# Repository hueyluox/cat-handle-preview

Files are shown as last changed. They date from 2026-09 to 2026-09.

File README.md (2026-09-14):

# 猫咪桶盖把手 · v3

两款照片参考的卡通猫咪把手，平底约 110 × 44 mm，三色分区。

- `*-A1-AMS.3mf`：拓竹 A1 + AMS lite 工程。
- `*-multicolor.3mf`：通用三色模型。
- `*-single.stl`：单色整体模型。

颜色顺序：1 暖白，2 橘色，3 深棕。使用 A1 工程前请按实际耗材重新切片。
模型尚未实物试打，粘贴前需检查桶盖平面尺寸和把手间隙。

在线预览：https://hueyluox.github.io/cat-handle-preview/

新作：不许上班 · 双猫屏幕摆件
- 页面：https://hueyluox.github.io/cat-handle-preview/monitor-cats/

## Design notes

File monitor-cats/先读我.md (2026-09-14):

# 不许上班 · 双猫屏幕摆件 v1

这是实际模型交付包，不是生成式效果图。猫的外形为照片参考的三色简化雕塑，尚未实物试打。

## 对应你家的两只猫
- 橘白：橘耳、橘色头顶和后背，窄白鼻纹、白胸、白前爪；条纹为浅凹槽。
- 三花：身体与整个后背全部白色，仅头和尾巴有橘/黑花纹，尾巴贴身。
- 全部模型只使用白、橘、黑三色。AMS lite 建议槽位 1 白、2 橘、3 黑。

## 从哪里开始
1. 先打印 `mounts/fit-check-16mm-PRINT.stl`。用户测量屏幕顶部厚度 15 mm，托座槽宽 16 mm。试槽能自然放上才继续，不能用力挤压显示屏；顶部若有弧度或斜面，仍需实物确认。
2. 两只都打印：用 Bambu Studio 打开 `pair/pair-A1-AMS.3mf`，按你实际的 PLA / PETG 等耗材重新选择材料并切片。目前工程按 Generic PLA 配置。
3. 单独打印可打开 `orange-cat/orange-cat-A1-AMS.3mf` 或 `calico-cat/calico-cat-A1-AMS.3mf`。
4. 白色托座用 `mounts/mounts-A1-white.3mf`，其中包括两只托座和一只试槽件。独立 STL 名称里的 PRINT 表示已设置推荐打印方向。
5. 猫和托座分开打印。清理支撑和边缘后，对齐猫底部浅槽与托座定位凸台，用适量胶或薄双面胶固定。浅槽只负责定位，不是卡扣锁紧结构。固化/贴牢后再安装。

## 文件说明
- `模型预览.html`：可离线打开的真实网格查看器，可转到背面核对纯白身体。
- `双猫-实际模型预览.png`：真实交付网格静态预览。
- `*-A1-AMS.3mf`：已有三色映射并经过实际切片的拓竹工程。
- `*-multicolor.3mf`：通用三色实体模型，便于自行重新配置切片。
- `*-single.stl`：单色整体版，STL 本身不保存颜色。
- `mounts/*-assembly.stl`：装配坐标用，请优先打印 PRINT 文件。
- `source/`：参数化生成脚本、网格预览代码与 A1 配置。

## 尺寸与当前切片估算
- 橘白猫体约 47.4 × 52.4 × 67.7 mm；含托座总高约 85.7 mm。
- 三花猫体约 87.7 × 51.2 × 51.7 mm；含托座总高约 69.7 mm。
- 托座：槽宽 16 mm，对应名义机身厚度 15 mm；橘白托座宽 40 mm，三花宽 60 mm。
- 两只同盘：约 21 小时 56 分钟，293.48 g。两只分别打印合计约 27 小时 6 分钟，363.54 g。
- 白色托座和试槽件：另约 1 小时 22 分钟，20.32 g。
- 上述时间/耗材来自 A1、0.4 mm 喷嘴、0.16 mm 层高、猫体 3 壁/15% gyroid、自动支撑、三色冲刷配置；耗材包含支撑、冲刷与擦料塔。
- 同盘可减少重复换色，但仍有较多冲刷；最终以你设备和耗材重新切片结果为准。

## 已完成的验证与实际限制
- 两只整体网格封闭、正体积、各一个连通实体；三色分件均封闭，复原体积相对误差小于 0.001%。
- 三花背部上方区域的有色实体相交体积为 0；已检查实际网格背面预览。
- 托座 16 mm 通槽、底部定位配合通过几何检查。
- 两个单猫工程、两猫同盘工程、白色托座工程均已用 Bambu Studio 2.8.2.61 实际切片，并确认没有超出打印区域。
- 尚未实物打印，托座适配、表面效果、去支撑难度、装配稳定性需通过试打确认。

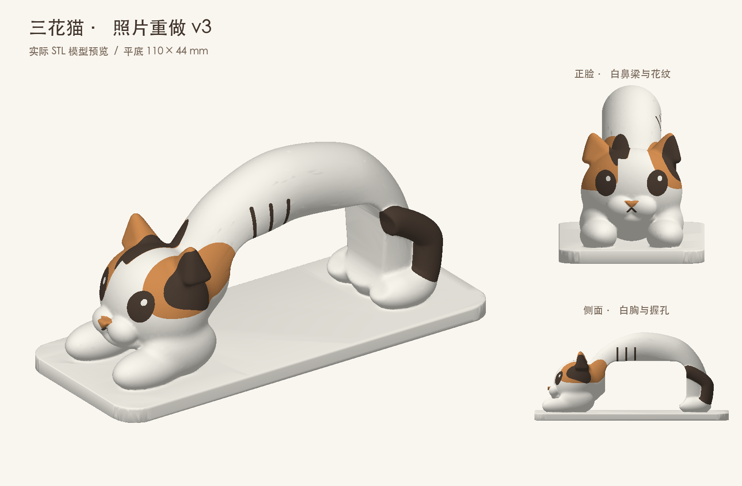
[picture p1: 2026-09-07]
previews/calico-cat.png

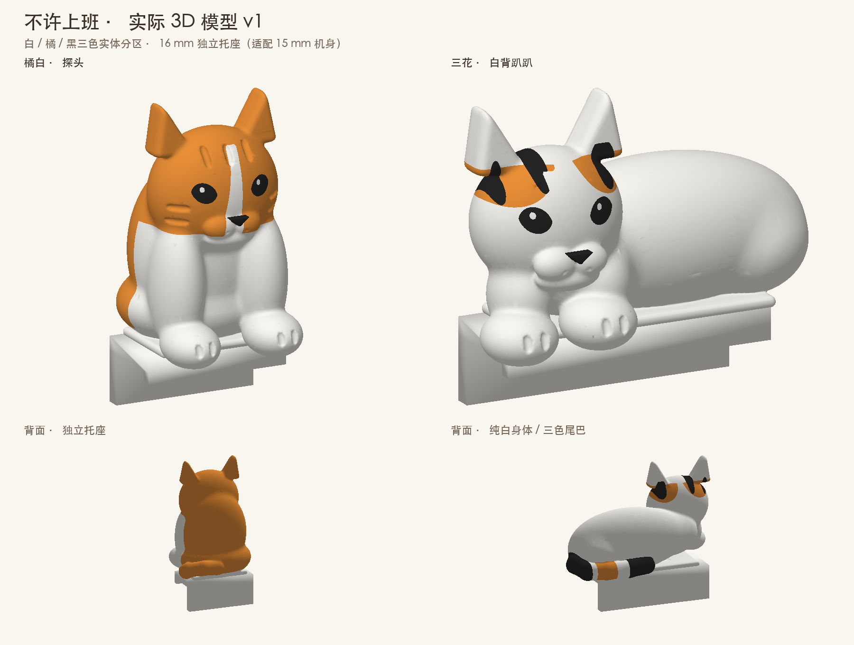
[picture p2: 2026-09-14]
monitor-cats/双猫-实际模型预览.png

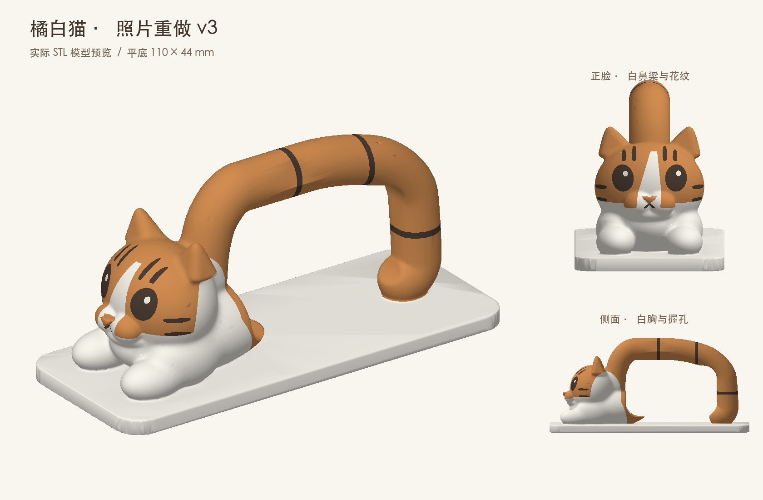
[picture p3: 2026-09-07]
previews/orange-cat.png

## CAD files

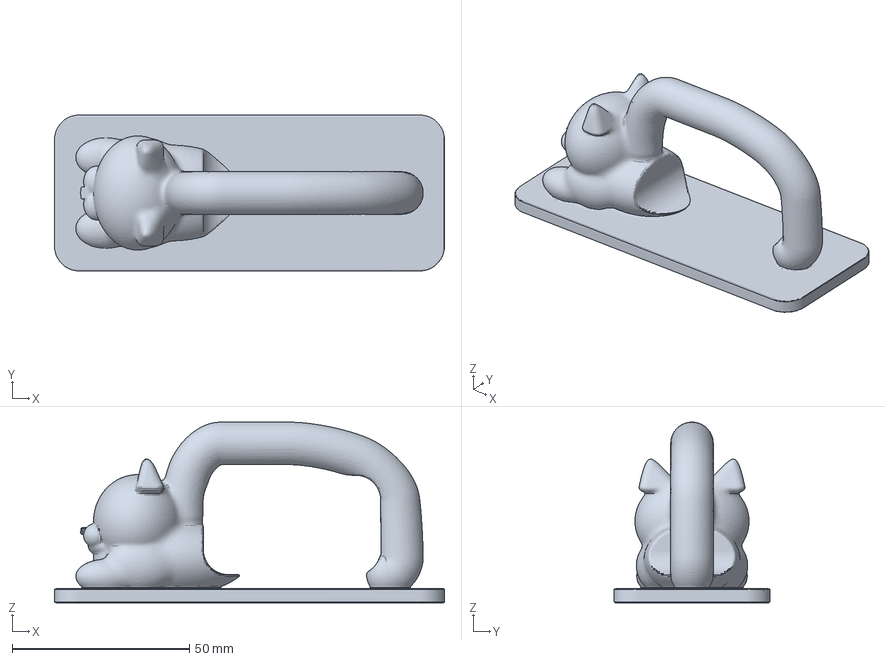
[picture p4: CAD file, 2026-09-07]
downloads/orange-cat-A1-AMS.3mf
110.0 x 44.0 x 51.0 mm

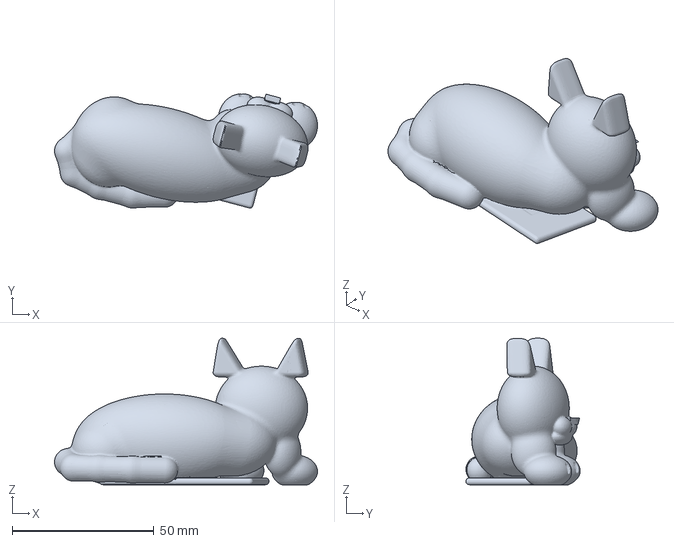
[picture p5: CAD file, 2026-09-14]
monitor-cats/calico-cat/calico-cat-A1-AMS.3mf
92.7 x 40.2 x 51.7 mm

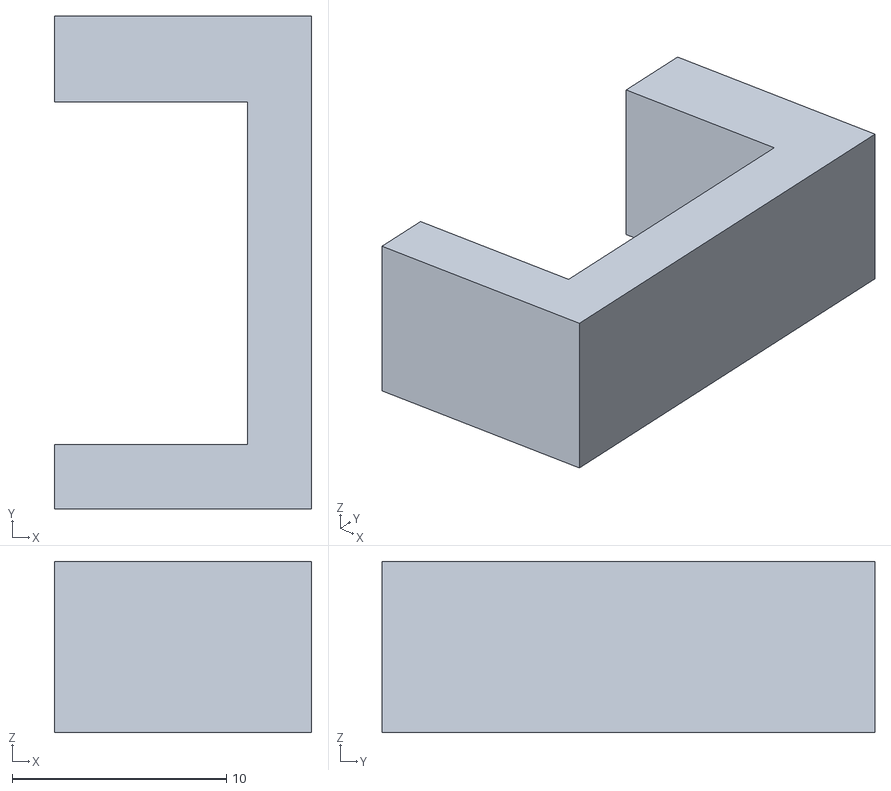
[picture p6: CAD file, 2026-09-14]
monitor-cats/mounts/fit-check-16mm-PRINT.stl
12.0 x 23.0 x 8.00

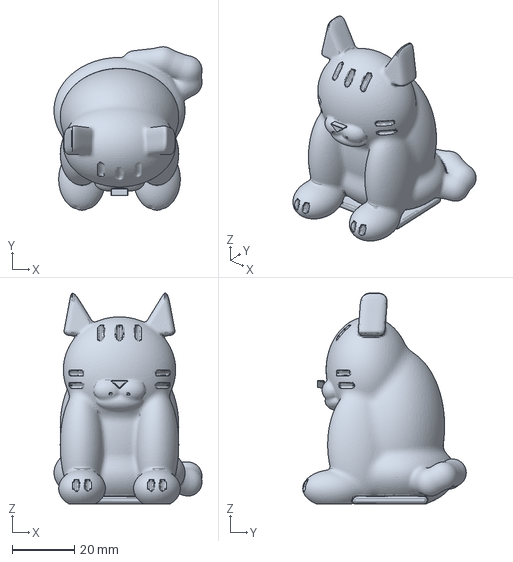
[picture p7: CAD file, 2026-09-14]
monitor-cats/orange-cat/orange-cat-A1-AMS.3mf
47.4 x 52.4 x 67.7 mm

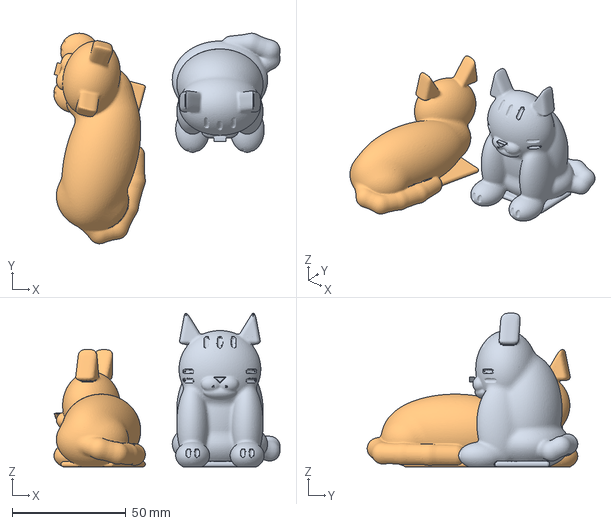
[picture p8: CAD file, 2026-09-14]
monitor-cats/pair/pair-A1-AMS.3mf
99.5 x 92.7 x 67.7 mm
orange-cat
calico-cat

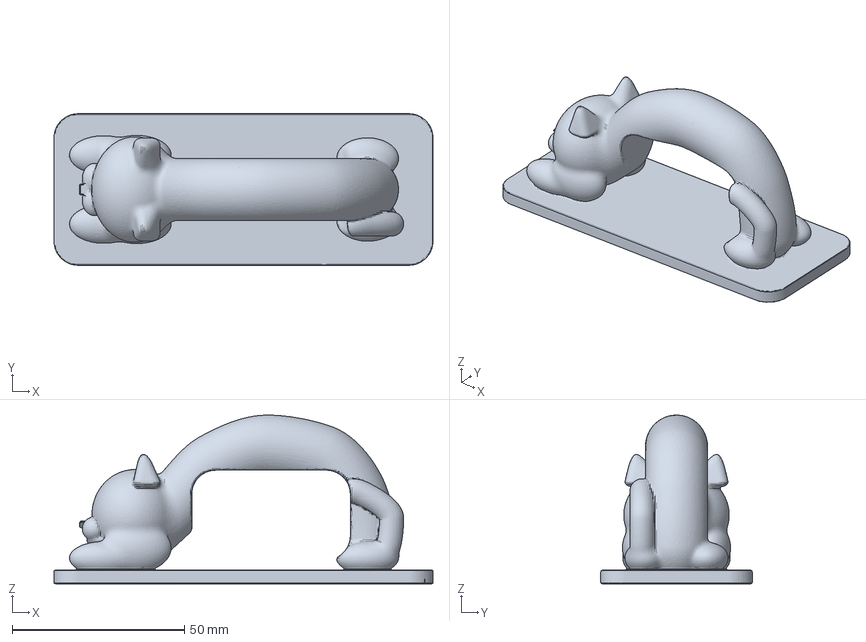
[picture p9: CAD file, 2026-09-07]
downloads/calico-cat-A1-AMS.3mf
110.0 x 44.0 x 49.0 mm

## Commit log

2026-09-07 Publish v3 cat handle model preview and downloads
    [calico-cat-A1-AMS.3mf, orange-cat-A1-AMS.3mf]
2026-09-14 Publish monitor-cats desk ornaments beside the v3 handle preview
    Add the finished dual-cat screen ornaments under monitor-cats/ and link them from the existing handle homepage without replacing v3 models or downloads.
    [calico-cat-A1-AMS.3mf, fit-check-16mm-PRINT.stl, orange-cat-A1-AMS.3mf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]
